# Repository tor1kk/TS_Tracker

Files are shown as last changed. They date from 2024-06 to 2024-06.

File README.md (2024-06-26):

# TheftShield_Tracker - GPS tracker with SMS communication 

## Brief

TheftShield Tracker is a device designed to provide real-time tracking and monitoring capabilities for valuable assets or vehicles. It leverages the power of GPS technology, GSM communication, and a microcontroller to offer a comprehensive solution for theft prevention and location tracking.

## Usage Instructions

To use the TheftShield Tracker, follow these steps:

1. **Insert SIM Card**:
    - Insert a nano SIM card into the SIM card slot of the device. Ensure that the SIM card does not have a PIN code set.

2. **Restart the Module**:
    - Restart the module by shorting the NRST and GND pins. This will reset the device and prepare it for operation.

3. **Wait for GPS Initialization**:
    - After restarting, the module will wait until the GPS module acquires a valid location fix. This might take a few minutes, especially in a new location or if the device has been off for a long time.

4. **GSM Module Network Registration**:
    - The GSM module will begin registering with the network. You can monitor the registration process by observing the LED indicator on the module:
        - **Fast blinking** (once every second): The module is searching for or trying to connect to a network.
        - **Slow blinking** (once every 3 seconds): The module is connected to the network.

5. **Send Commands**:
    - Once the device is connected to the network, you can start sending SMS commands to it. Note that the first command you send is usually ignored, so you might need to send it a second time.
    
## Features

The TheftShield Tracker offers the following key features:

- **GPS Tracking**: The device is equipped with a NEO-6M GPS module from u-blox, allowing it to accurately determine its geographic coordinates (latitude and longitude). The NEO-6M is a high-performance GPS receiver with excellent sensitivity and low power consumption.
- **GSM Communication**: The SIM800C GSM module from SIMCOM enables the device to send and receive SMS messages, facilitating remote control and data transmission. The SIM800C is a quad-band GSM/GPRS module that supports voice, SMS, and data transfer.
- **Real-Time Location Updates**: Upon receiving an SMS command, the device can promptly send its current GPS coordinates to a specified phone number.
- **Battery Voltage Monitoring**: The device can measure and report the battery voltage level to a specified phone number, ensuring timely monitoring of the power supply. It uses the built-in Analog-to-Digital Converter (ADC) of the STM32F401RCT6 microcontroller to measure the battery voltage.
- **RTC Alarm Configuration**: Users can set an alarm time through an SMS command. When the alarm triggers, the device will automatically send its GPS coordinates to a predefined phone number. The device utilizes the Real-Time Clock (RTC) peripheral of the STM32F401RCT6 microcontroller to set and manage the alarm.
- **Alarm Time Management**: The device allows users to request the current configured alarm time or deactivate the alarm through SMS commands.
- **Power Management**: The device can enter low-power sleep mode when idle, conserving battery life and extending operational duration. The STM32F401RCT6 microcontroller supports various low-power modes, allowing the device to minimize power consumption when not actively performing tasks.

**Here's a table of the supported SMS commands:**

| Command | Format | Description |
|---|---|---|
| Get GPS Coordinates  | 1: | Sends the device's current GPS coordinates to the specified phone number. |
| Get Voltage | 2: | Sends the battery voltage level to the specified phone number. |
| Set Alarm Time | 3:time: | Sets the RTC alarm time in 24-hour format (e.g., 3:2359: for 11:59 PM). The device will send GPS coordinates to the specified phone number when the alarm triggers. |
| Get Alarm Time | 4: | Requests the currently configured RTC alarm time. |
| Deactivate Alarm | 5: | Deactivates the RTC alarm. |

The device is powered by a backup battery and incorporates power management features to extend its operational lifetime. It utilizes the FreeRTOS real-time operating system to manage tasks and ensure efficient resource allocation.

With its combination of GPS tracking, GSM communication, and remote control capabilities, the TheftShield Tracker offers a reliable and versatile solution for asset tracking, theft prevention, and location monitoring applications.

## Photos

### 3D Model

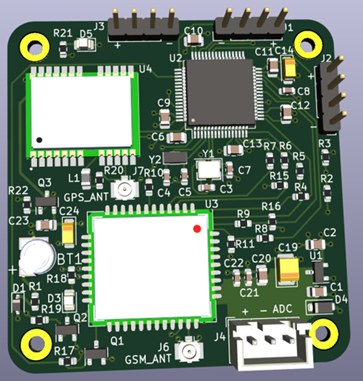
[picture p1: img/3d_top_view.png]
3D Model GPS tracker front view

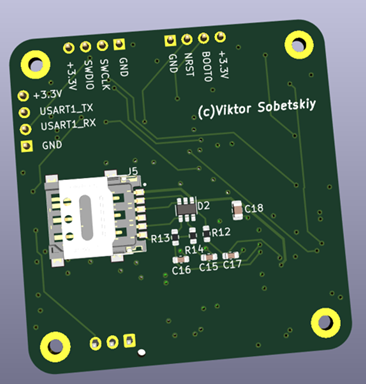
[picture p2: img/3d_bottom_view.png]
3D Model GPS tracker bottom view


### Real PCB

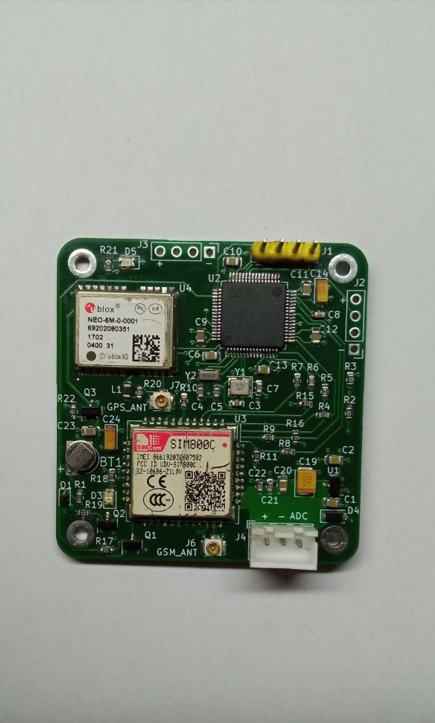
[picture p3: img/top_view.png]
Real PCB GPS tracker front view
<br/> 
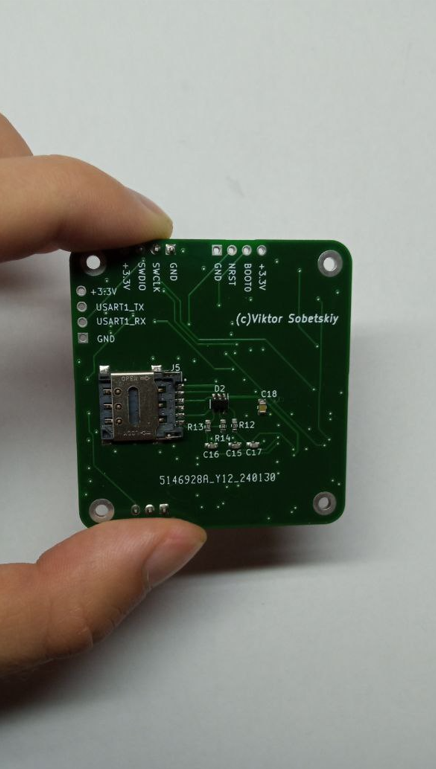
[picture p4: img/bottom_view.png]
Real PCB GPS tracker bottom view
 

# Project Structure

The project is organized into two main parts:

TheftShield_Tracker/<br/>
├── hardware/<br/>
│ └── README.md<br/>
└── software/<br/>
│└── README.md<br/>
└──
### hardware/
- **README.md**: Contains information about the hardware design.

### software/
- **README.md**: Contains information about the software implementation.

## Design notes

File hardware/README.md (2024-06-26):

# Hardware

## Brief

This directory contains the hardware design files for the TheftShield_Tracker project. The project utilizes the following key components:

**Microcontroller**

- STM32F401RCT6 - An ARM Cortex-M4 32-bit microcontroller from STMicroelectronics. It serves as the main control unit, handling task scheduling, communication with peripherals, and executing the application logic.

**GPS Module**

- NEO-6M - A high-performance GPS receiver module from u-blox. It provides accurate positioning data and enables tracking capabilities.

**GSM/GPRS Module**

- SIM800C - A quad-band GSM/GPRS module from SIMCOM. It enables SMS communication for remote control and data transmission.

**Other Components**

- MCP1700 - A low-dropout voltage regulator for providing a stable 3.3V supply.
- Backup battery holder and protection circuitry.
- Assorted passive components (resistors, capacitors, etc.).

## Design Files

- The KiCad project files containing the complete hardware design.
- [GPS tracker schematic](./TheftShield_Tracker.pdf) - A PDF version of the schematic.

## Block diagram

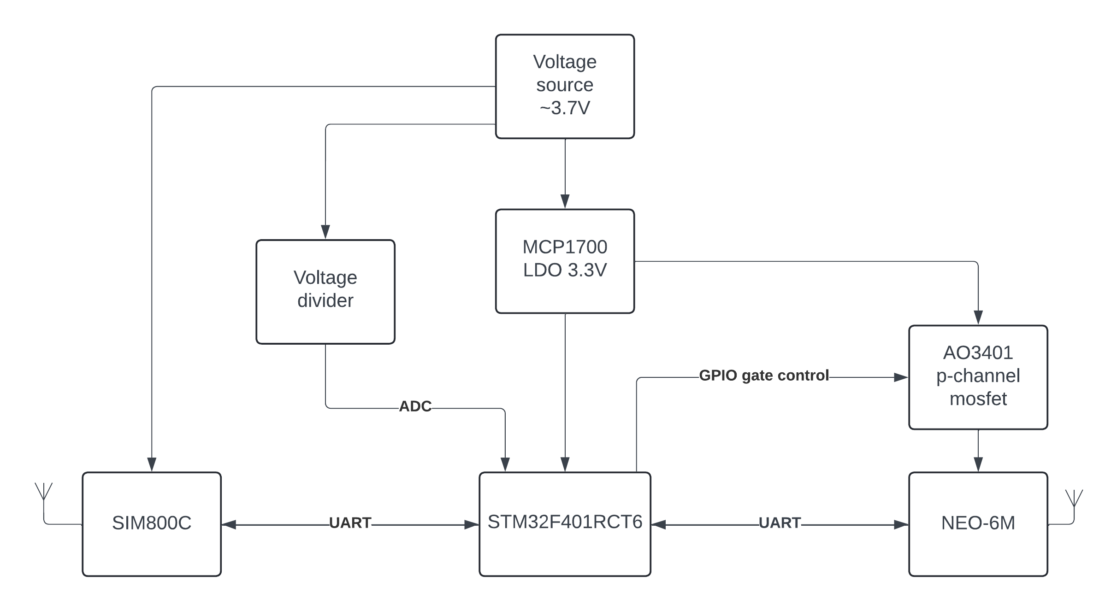
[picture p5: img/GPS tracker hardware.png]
GPS tracker hardware block diagram


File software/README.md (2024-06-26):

# Software

## Brief

The primary goal of this software is to receive commands from the SIM800C module, parse these commands, perform various actions (e.g., send GPS coordinates from the NEO-6M module), and send responses via the SIM800C module on the STM32F401RCT6 microcontroller.
For this project, appropriate drivers were written: [HAL-based NEO-6M driver](https://github.com/tor1kk/neo-6m) and [HAL-based SIM800C driver](https://github.com/tor1kk/sim800).

## How its work

After peripheral intitialisation, the current time is set for the RTC peripheral. A global variable (`currentTime`) is initialized to 0, and the program waits for this variable to become non-zero. This variable is modified in the ISR callback after receiving data from the GPS module, where the actual current time is obtained. Afterward, FreeRTOS tasks are created, and the scheduler is started. All tasks are located in the `application_tasks.c` file.

The first task to run is the one that resets and configures the SIM800C module (`vSim800ResetTask`).

Whenever an SMS message is received, the appropriate callback from the SIM800C driver (`SIM800_RcvdSMSCallBack`) is triggered. In this callback, the message and phone number are copied to send this data to a special task (`vCmdProcessTask`) via a queue (`xCommandQueue`). After that, this task is awakened from the blocked state to the ready state. This task parses the message; all commands should be digits, so the received command is compared with the expected commands. If they match, the appropriate action occurs. If the command doesn't match, the message `"Unknown command!"` is transmitted.

Users can send commands to get GPS coordinates, get the voltage on the ADC pin, set the time when coordinates will be received, get a notification for this time, or delete the notification.

### Tasks

- **vSim800ResetTask** - Resets and configures the SIM800 module (priority: `4`)
- **vCmdProcessTask** - Parses received commands (priority: `3`)
- **vSendSMSTask** - Transmits SMS messages (priority: `2`)
- **vConfigRTCAlarmTask** - Configures the RTC alarm (priority: `1`)
- **vSendGPSTask** - Gets the current GPS coordinates and sends them to **vSendSMSTask** (priority: `1`)
- **vSendVoltageTask** - Gets the voltage on the ADC pin and sends it to **vSendSMSTask** (priority: `1`)
- **vSendCurrentAlarmTask** - Gets the current RTC alarm and sends it to **vSendSMSTask** (priority: `1`)

Any data that must be transmitted to the user is sent to the `xSMSToSendQueue`, and `vSendSMSTask` receives this data and sends it to the user.

`vConfigRTCAlarmTask` waits for the time at which the RTC alarm must occur in the `xTimeToRTCAlarmQueue`. It should be noted that when the RTC alarm triggers, the phone number contained in the `phoneNumberForNotify` buffer, which was placed there by `vCmdProcessTask`, is used. This is the number from which the notification command was received.

`vSendGPSTask` waits for numbers to which coordinates must be sent in the `xNumbersToSendGPSQueue`. In this task, the NEO-6M module is powered on and GPS coordinates are awaited in the `xGPSCoordinatesQueue`, which are set in the `NEO6M_RMCCallBack` callback from the NEO-6M driver. Then, an SMS message with the coordinates and number is sent to `vSendSMSTask`.

`vSendVoltageTask` waits for numbers to which the voltage must be sent in the `xNumbersToSendVoltageQueue`. In this task, an ADC conversion is initiated and the voltage value is awaited in the `xADCValueQueue`, which is placed in the `HAL_ADC_ConvCpltCallback`. Then, an SMS message with the voltage and number is sent to `vSendSMSTask`.

`vSendCurrentAlarmTask` waits for a notification from `vCmdProcessTask`. It gets the current RTC alarm and sends this information to the number in the `phoneNumberForNotify` buffer. 

### Block diagram

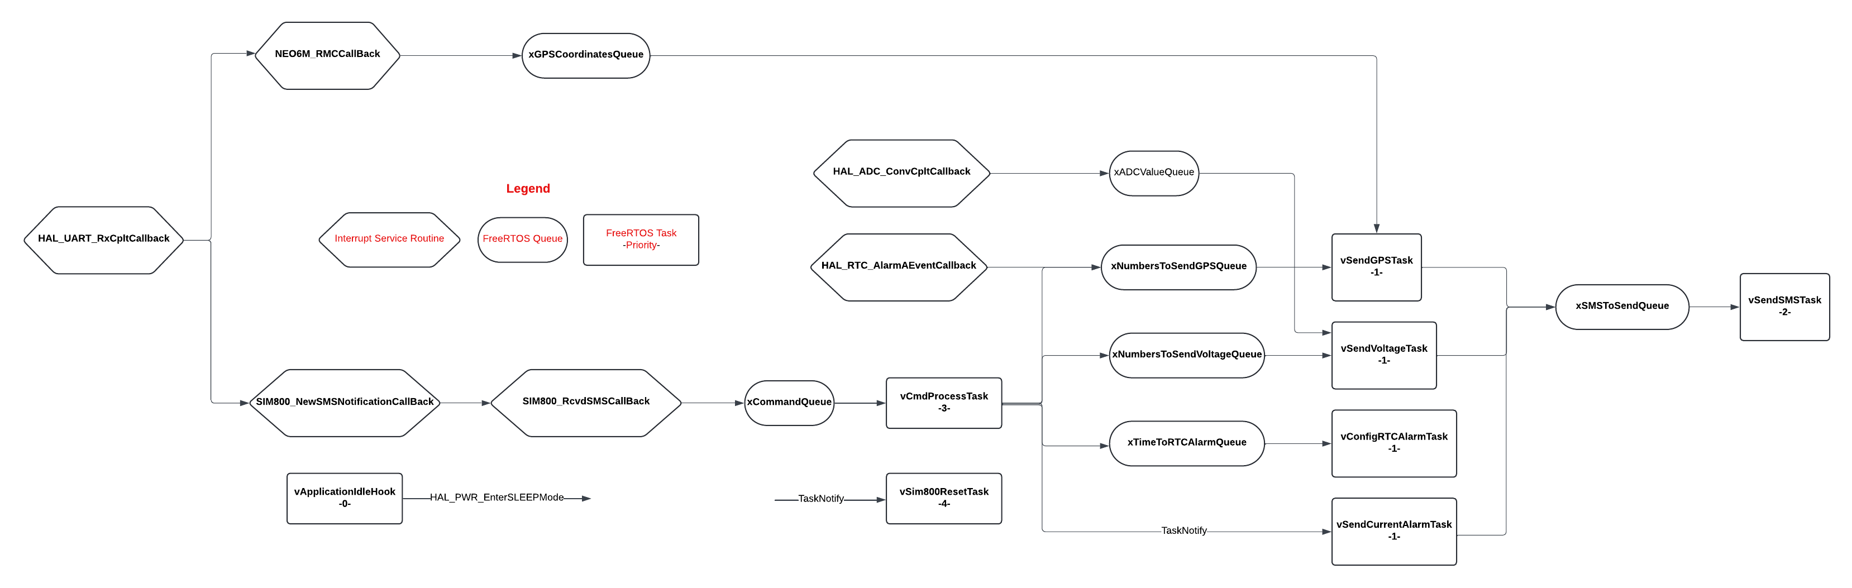
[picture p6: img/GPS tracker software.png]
GPS tracker FreeRTOS software block diagram


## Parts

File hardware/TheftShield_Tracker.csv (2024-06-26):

Reference | Value | Footprint | Qty
BT1 | Battery_Cell | footprints:SEIKO_ML414H_IV01E | 1
C1,C2,C20 | 1uF | Capacitor_SMD:C_0805_2012Metric | 3
C3,C4,C5,C7,C22 | 12pF | Capacitor_SMD:C_0603_1608Metric | 5
C6,C9,C10,C11,C12,C13,C18,C23 | 100nF | Capacitor_SMD:C_0805_2012Metric | 8
C8,C14,C24 | 4,7uF | -- mixed values -- | 3
C15,C16,C17,C21 | 22pF | Capacitor_SMD:C_0603_1608Metric | 4
C19 | 100uF | Capacitor_Tantalum_SMD:CP_EIA-3528-21_Kemet-B | 1
D1 | 1N5819WS | Diode_SMD:D_SOD-323 | 1
D2 | ESDA6V1-5SC6 | Package_TO_SOT_SMD:SOT-23-6 | 1
D3,D5 | ncd0805r1 | LED_SMD:LED_0805_2012Metric | 2
D4 | BZT52B5V1 | Diode_SMD:D_SOD-123F | 1
H1,H2,H3,H4 | MountingHole_Pad | MountingHole:MountingHole_2.2mm_M2_Pad | 4
J1,J2,J3 | Conn_01x04_Pin | Connector_PinHeader_2.54mm:PinHeader_1x04_P2.54mm_Vertical | 3
J4 | Conn_01x03_Socket | Connector_JST:JST_XH_B3B-XH-AM_1x03_P2.50mm_Vertical | 1
J5 | SIM8060-6-1-14-00-A | footprints:GCT_SIM8060-6-1-14-00-A | 1
J6,J7 | Conn_Coaxial | Connector_Coaxial:U.FL_Hirose_U.FL-R-SMT-1_Vertical | 2
L1 | 22uH | Inductor_SMD:L_0805_2012Metric | 1
Q1,Q2 | AO3402 | Package_TO_SOT_SMD:SOT-23 | 2
Q3 | AO3401A | Package_TO_SOT_SMD:SOT-23 | 1
R1,R4,R5,R6,R7,R8,R9,R10,R18,R21 | 1K | Resistor_SMD:R_0603_1608Metric | 10
R2,R3,R17,R19,R22 | 47K | Resistor_SMD:R_0603_1608Metric | 5
R11,R15,R16 | 5.1K | Resistor_SMD:R_0603_1608Metric | 3
R12,R13,R14 | 51R | Resistor_SMD:R_0603_1608Metric | 3
R20 | 22R | Resistor_SMD:R_0603_1608Metric | 1
U1 | MCP1700x-330xxTT | Package_TO_SOT_SMD:SOT-23 | 1
U2 | STM32F401RCTx | Package_QFP:LQFP-64_10x10mm_P0.5mm | 1
U3 | SIM800C | RF_GSM:SIMCom_SIM800C | 1
U4 | NEO-6M-GPS | footprints:XCVR_NEO-6M-GPS | 1
Y1 | Crystal_GND24 | Crystal:Crystal_SMD_3225-4Pin_3.2x2.5mm | 1
Y2 | 32.768kHz | Crystal:Crystal_SMD_3215-2Pin_3.2x1.5mm | 1

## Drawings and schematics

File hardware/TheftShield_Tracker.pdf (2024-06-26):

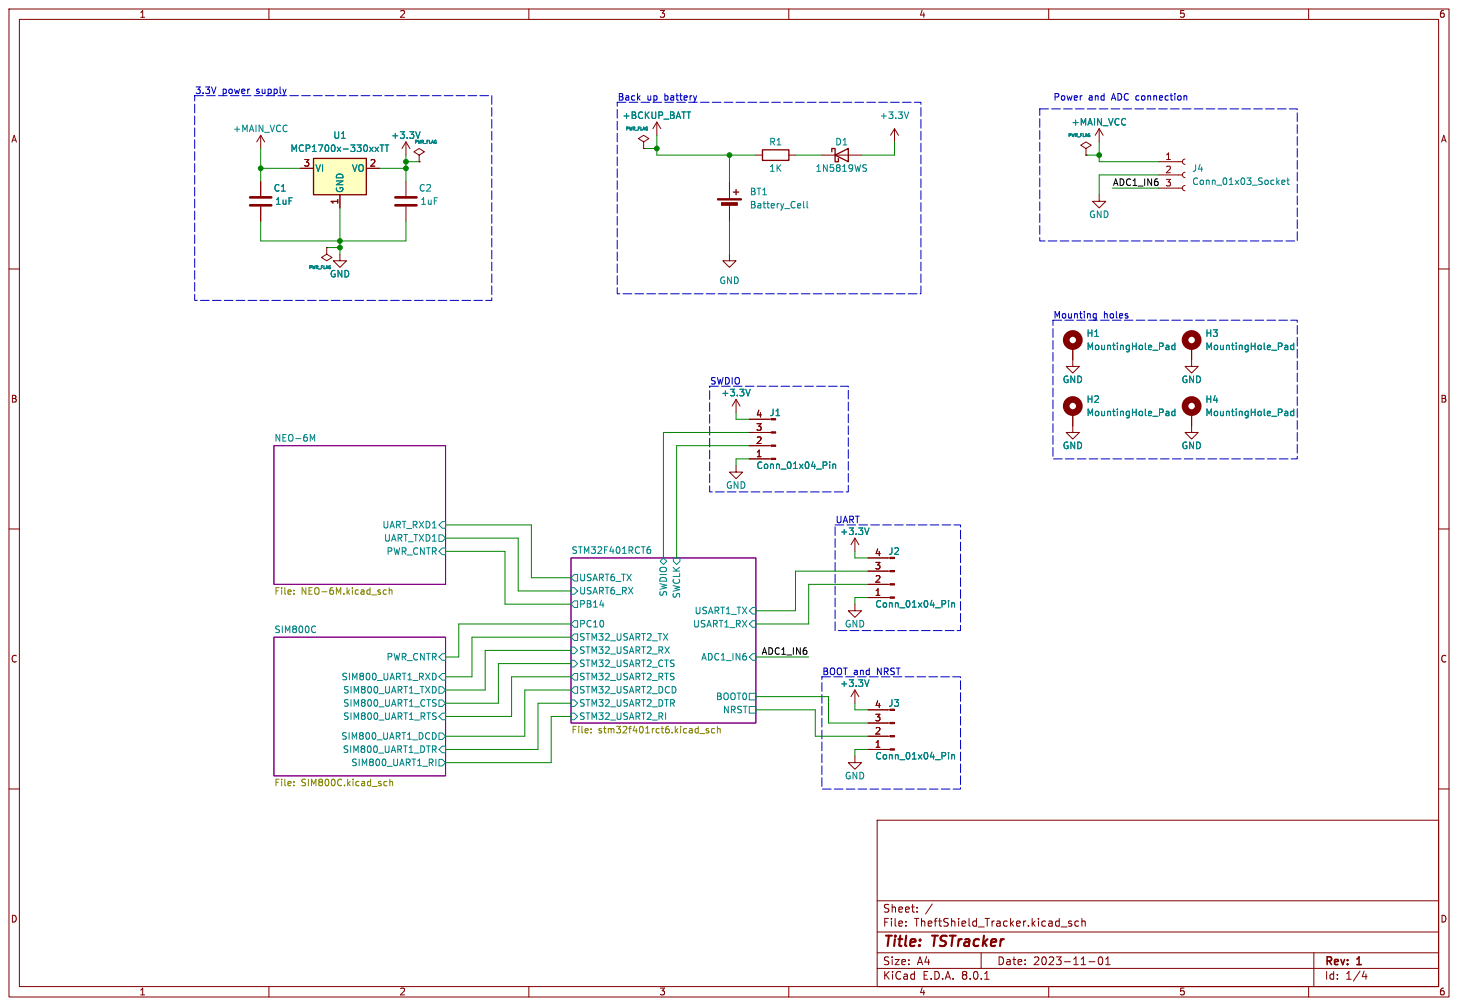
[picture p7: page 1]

Id: 1/4 Title: TSTracker File: TheftShield_Tracker.kicad_sch Sheet: / UART_RXD1 UART_TXD1 PWR_CNTR

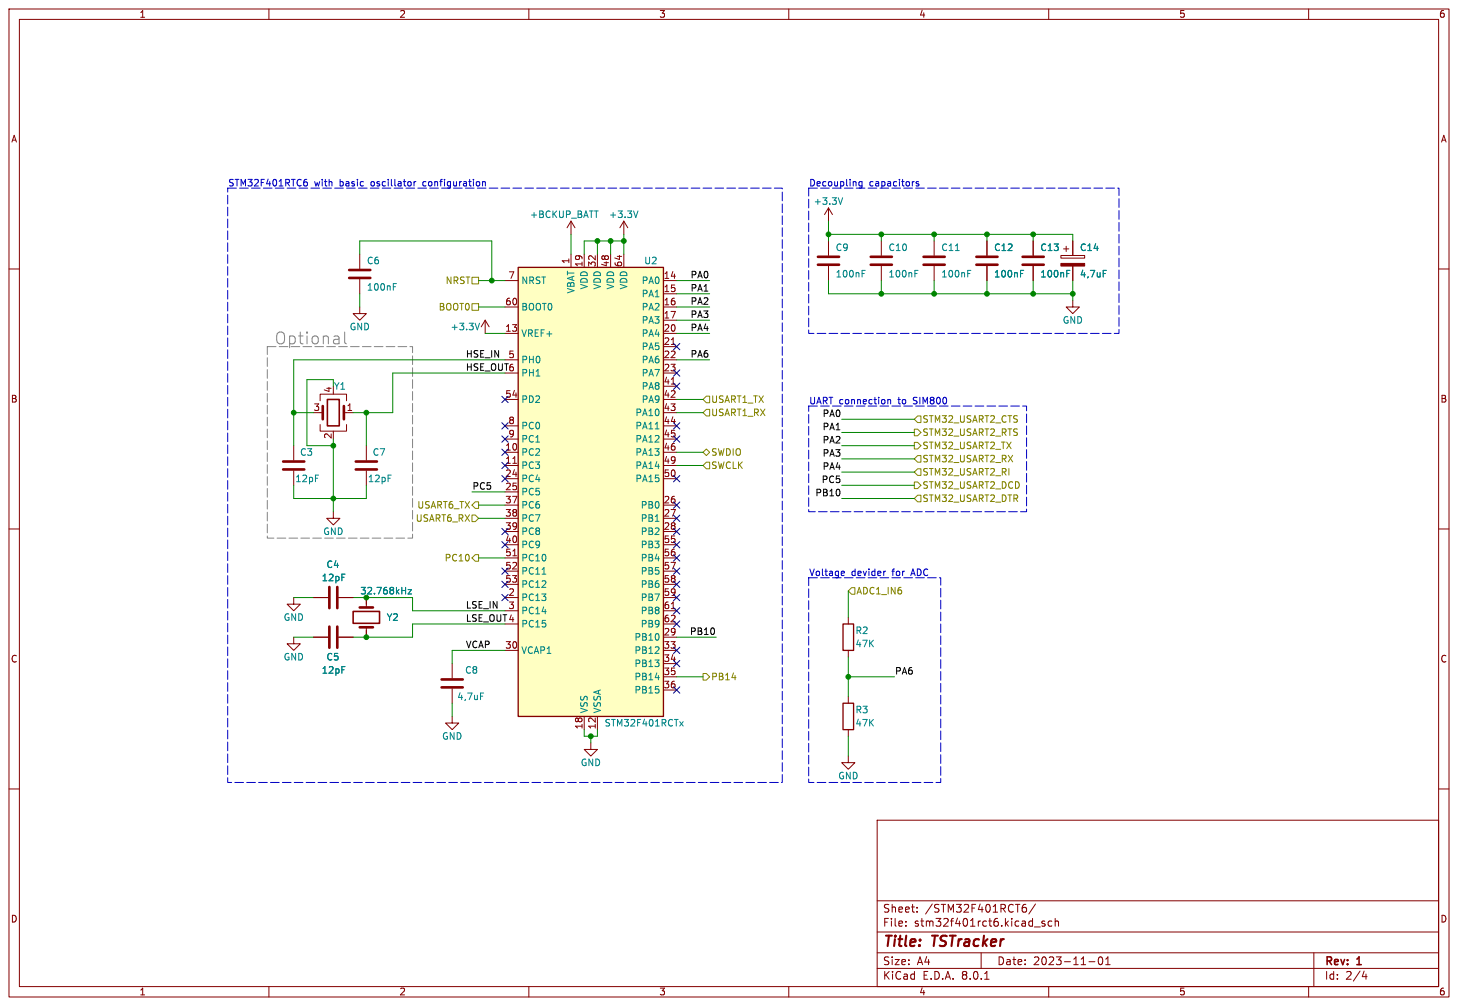
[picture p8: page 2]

1 PC2 10 PC3 11 VSSA 12 VREF+ 13 PA0 14 PA1 15 PA2 16 PA3 17 VSS 18 VDD 19 PC13 2 PA4 20 PA5 21 PA6 22 PA7 23 PC4 24 PC5 25 PB0 26 PB1 27 PB2 28 PB10 29 PC14 3 VCAP1 30 VDD 32 PB12 33 PB13 34 PB14 35 PB15 36 PC6 37 PC7 38 PC8 39 PC15 4 PC9 40 PA8 41 PA9 42 PA10 43 PA11 44 PA12 45 PA13 46 VDD 48 PA14 49 PH0 5 PA15 50 PC10 51 PC11 52 PC12 53 PD2 54 PB3 55 PB4 56 PB5 57 PB6 58 PB7 59 PH1 6 BOOT0 60 PB8 61 PB9 62 VDD 64 NRST 7 PC0 8 PC1 9 U2 STM32F401RCTx GND GND

Id: 2/4 Title: TSTracker File: stm32f401rct6.kicad_sch Sheet: /STM32F401RCT6/

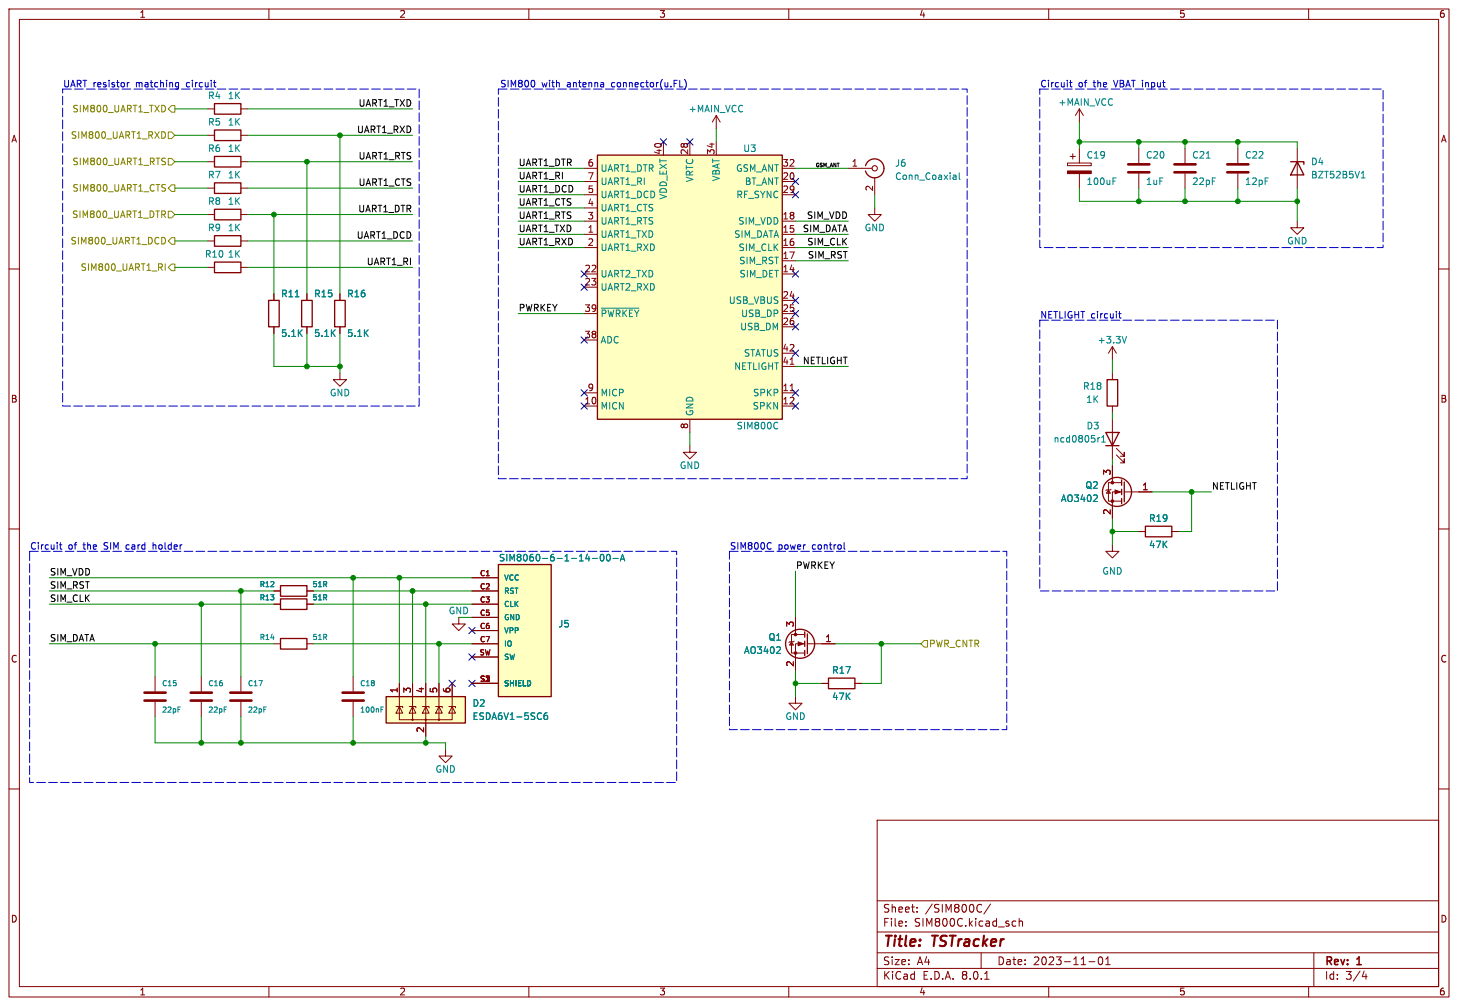
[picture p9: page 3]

SIM800 with antenna connector(u.FL) D2ESDA6V1-5SC6
J6Conn_Coaxial GND
GSM_ANT NETLIGHT SIM_VDD

Id: 3/4 Title: TSTracker File: SIM800C.kicad_sch Sheet: /SIM800C/ C17

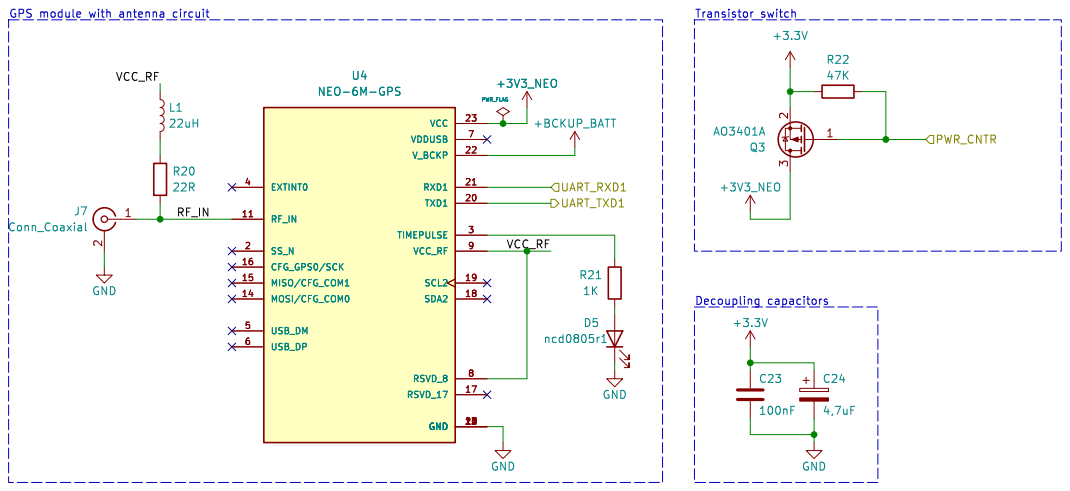
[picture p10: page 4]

Id: 4/4 Title: TSTracker File: NEO-6M.kicad_sch Sheet: /NEO-6M/

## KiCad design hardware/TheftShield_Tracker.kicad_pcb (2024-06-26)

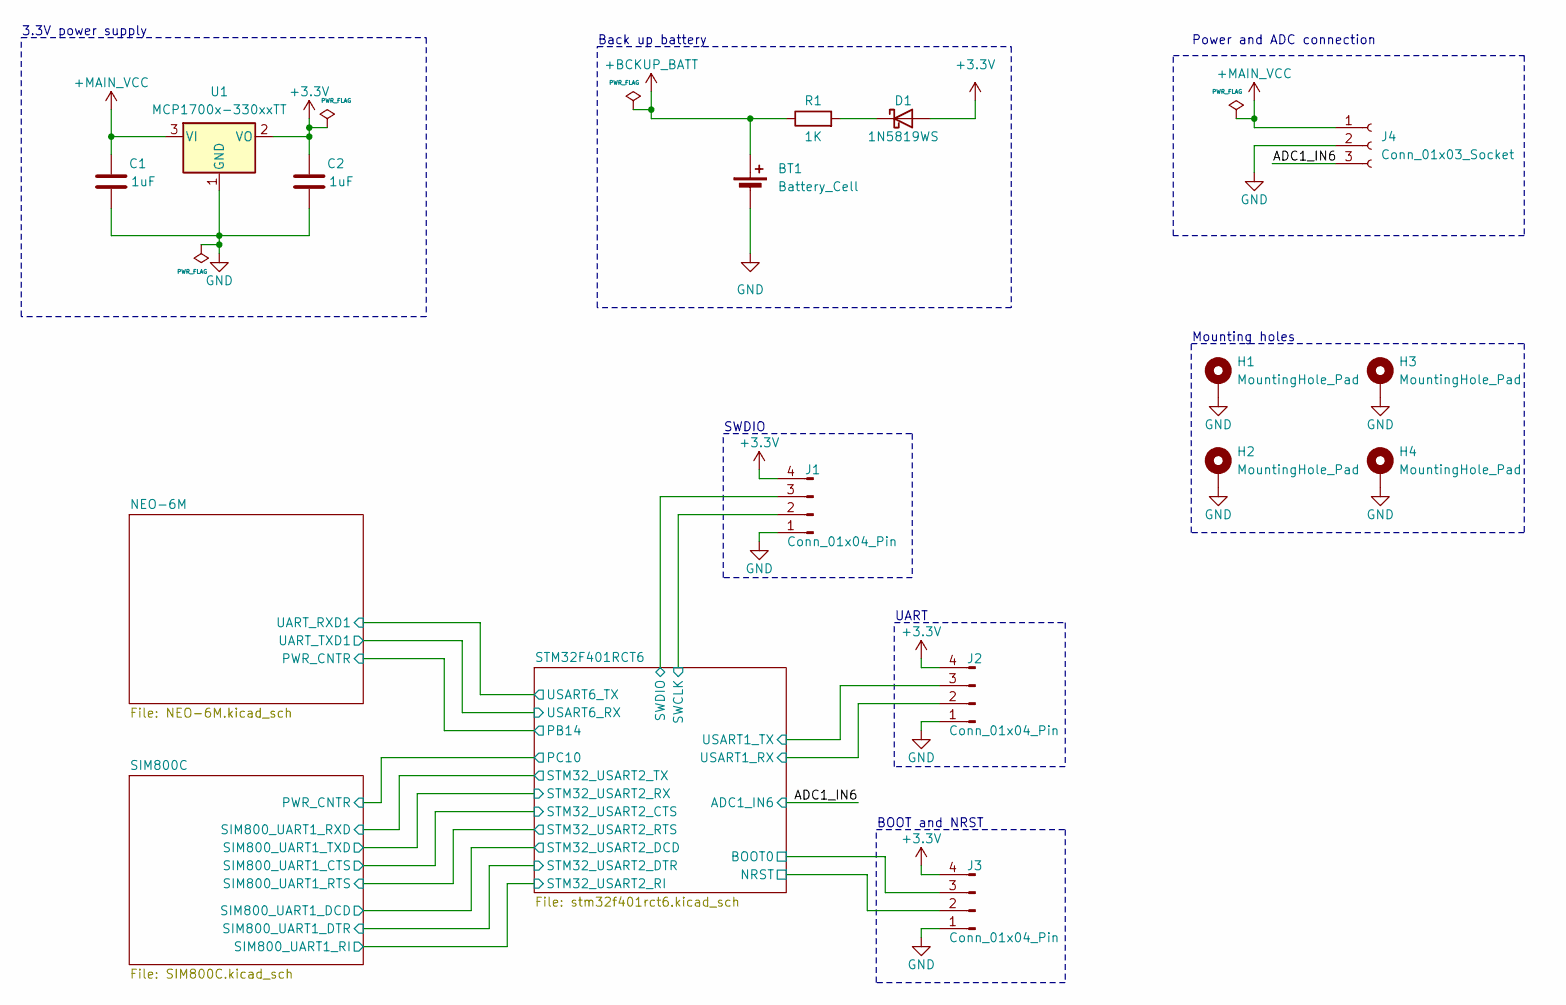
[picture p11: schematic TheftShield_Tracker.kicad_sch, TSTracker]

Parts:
BT1: Battery_Cell; SEIKO_ML414H_IV01E
C1, C2: 1uF; C_0805_2012Metric
D1: 1N5819WS; D_SOD-323
H1, H2, H3, H4: MountingHole_Pad; MountingHole_2.2mm_M2_Pad
J1, J2, J3: Conn_01x04_Pin; PinHeader_1x04_P2.54mm_Vertical
J4: Conn_01x03_Socket; JST_XH_B3B-XH-AM_1x03_P2.50mm_Vertical
R1: 1K; R_0603_1608Metric
U1: MCP1700x-330xxTT; SOT-23

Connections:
+3.3V: C2.2, D1.2 (A), J1.4, J2.4, J3.4, U1.2 (VO); also elsewhere on the board
+BCKUP_BATT: BT1.1 (+), R1.1; also elsewhere on the board
+MAIN_VCC: C1.2, J4.1, U1.3 (VI); also elsewhere on the board
/ADC1_IN6: J4.3; also elsewhere on the board
/STM32F401RCT6/BOOT0: J3.3; also elsewhere on the board
/STM32F401RCT6/NRST: J3.2; also elsewhere on the board
/STM32F401RCT6/SWCLK: J1.2; also elsewhere on the board
/STM32F401RCT6/SWDIO: J1.3; also elsewhere on the board
/STM32F401RCT6/USART1_RX: J2.2; also elsewhere on the board
/STM32F401RCT6/USART1_TX: J2.3; also elsewhere on the board
GND: BT1.2 (-), C1.1, C2.1, H1.1, H2.1, H3.1, H4.1, J1.1, J2.1, J3.1, J4.2, U1.1 (GND); also elsewhere on the board
unnamed: D1.1 (K), R1.2

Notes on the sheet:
Power and ADC connection
BOOT and NRST
Mounting holes
SWDIO
Back up battery
3.3V power supply
UART

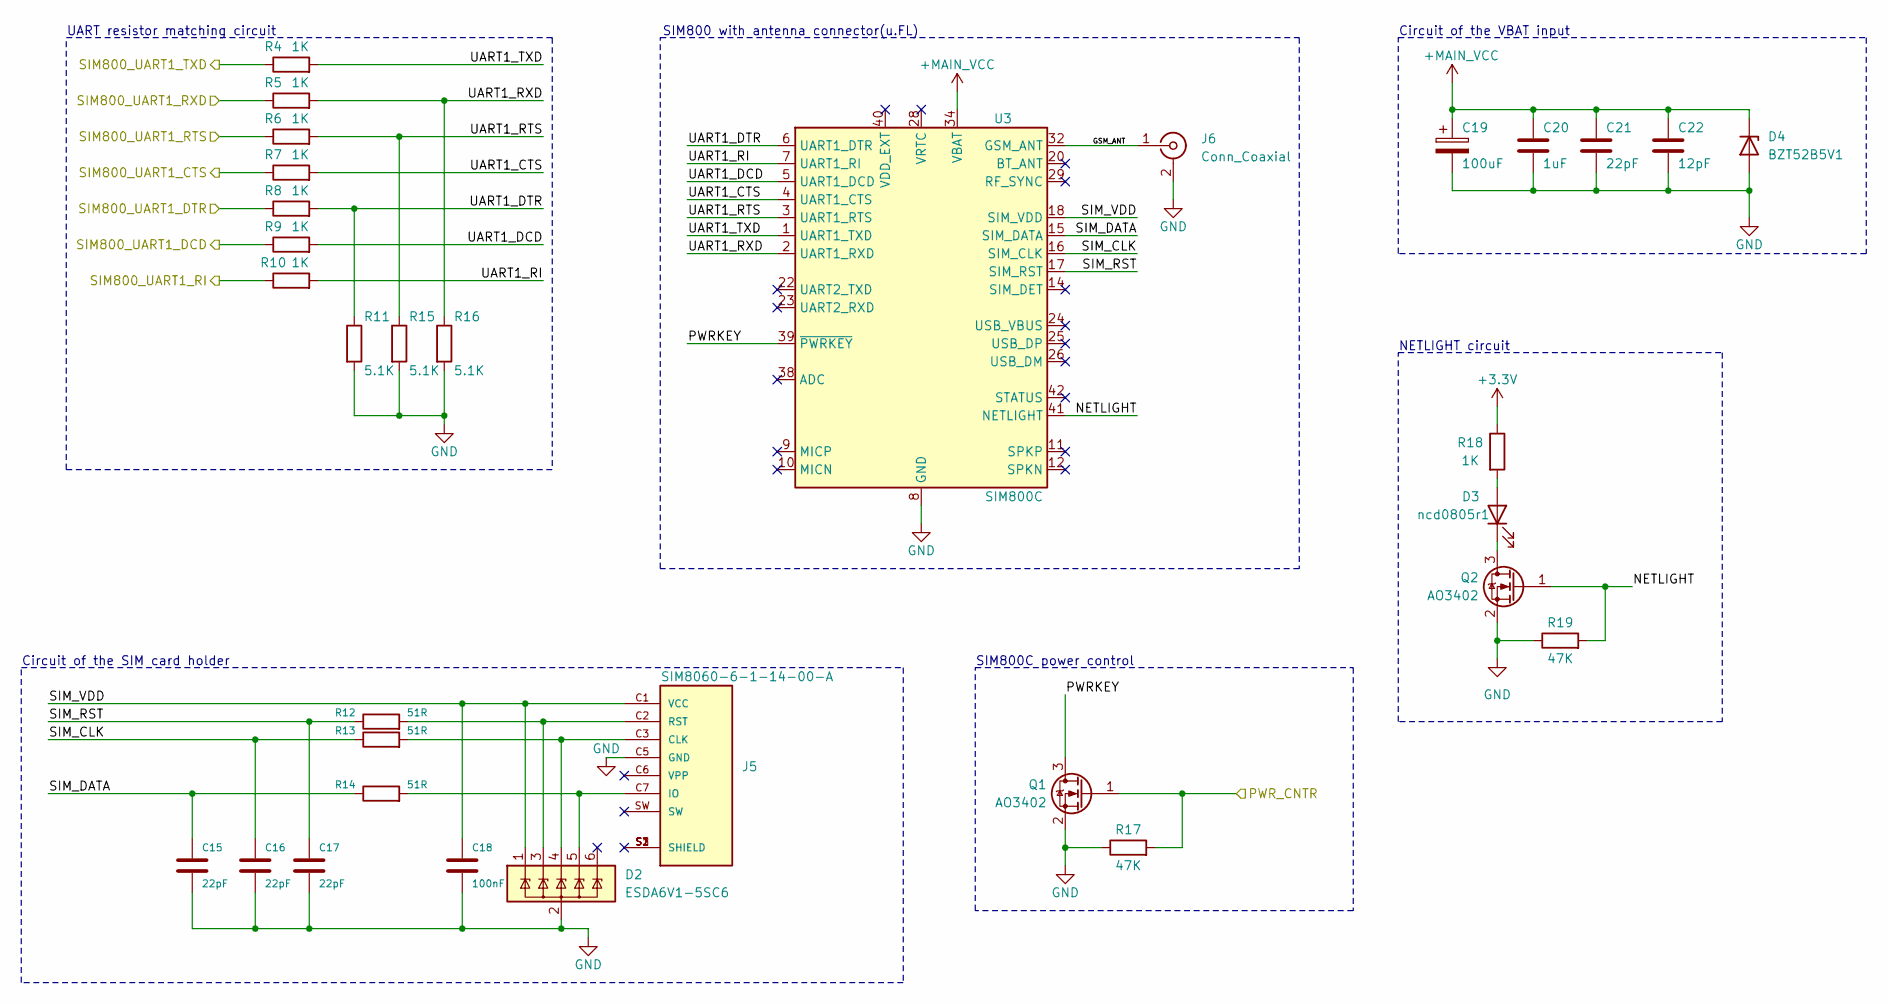
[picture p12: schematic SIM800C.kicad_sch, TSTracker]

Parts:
C15, C16, C17, C21: 22pF; C_0603_1608Metric
C18: 100nF; C_0805_2012Metric
C19: 100uF; CP_EIA-3528-21_Kemet-B
C20: 1uF; C_0805_2012Metric
C22: 12pF; C_0603_1608Metric
D2: ESDA6V1-5SC6; SOT-23-6
D3: ncd0805r1; LED_0805_2012Metric
D4: BZT52B5V1; D_SOD-123F
J5: SIM8060-6-1-14-00-A; GCT_SIM8060-6-1-14-00-A; PARTREV A
J6: Conn_Coaxial; U.FL_Hirose_U.FL-R-SMT-1_Vertical
Q1, Q2: AO3402; SOT-23
R4, R5, R6, R7, R8, R9, R10, R18: 1K; R_0603_1608Metric
R11, R15, R16: 5.1K; R_0603_1608Metric
R12, R13, R14: 51R; R_0603_1608Metric
R17, R19: 47K; R_0603_1608Metric
U3: SIM800C; SIMCom_SIM800C

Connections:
+3.3V: R18.1; also elsewhere on the board
+MAIN_VCC: C19.1, C20.1, C21.1, C22.1, D4.1 (K), U3.34 (VBAT), U3.35 (VBAT); also elsewhere on the board
/SIM800C/GSM_ANT: J6.1 (In), U3.32 (GSM_ANT)
/SIM800C/NETLIGHT: Q2.1 (G), R19.2, U3.41 (NETLIGHT)
/SIM800C/PWRKEY: Q1.3 (D), U3.39 (~PWRKEY)
/SIM800C/PWR_CNTR: Q1.1 (G), R17.2; also elsewhere on the board
/SIM800C/SIM_CLK: C16.1, R13.1, U3.16 (SIM_CLK)
/SIM800C/SIM_DATA: C15.1, R14.1, U3.15 (SIM_DATA)
/SIM800C/SIM_RST: C17.1, R12.1, U3.17 (SIM_RST)
/SIM800C/SIM_VDD: C18.1, D2.1 (IO1), J5.C1 (VCC), U3.18 (SIM_VDD)
/SIM800C/UART1_CTS: R7.2, U3.4 (UART1_CTS)
/SIM800C/UART1_DCD: R9.2, U3.5 (UART1_DCD)
/SIM800C/UART1_DTR: R8.2, R11.1, U3.6 (UART1_DTR)
/SIM800C/UART1_RI: R10.2, U3.7 (UART1_RI)
/SIM800C/UART1_RTS: R6.2, R15.1, U3.3 (UART1_RTS)
/SIM800C/UART1_RXD: R5.2, R16.1, U3.2 (UART1_RXD)
/SIM800C/UART1_TXD: R4.2, U3.1 (UART1_TXD)
/STM32F401RCT6/PA0: R7.1; also elsewhere on the board
/STM32F401RCT6/PA1: R6.1; also elsewhere on the board
/STM32F401RCT6/PA2: R5.1; also elsewhere on the board
/STM32F401RCT6/PA3: R4.1; also elsewhere on the board
/STM32F401RCT6/PA4: R10.1; also elsewhere on the board
/STM32F401RCT6/PB10: R8.1; also elsewhere on the board
/STM32F401RCT6/PC5: R9.1; also elsewhere on the board
GND: C15.2, C16.2, C17.2, C18.2, C19.2, C20.2, C21.2, C22.2, D2.2 (GND), D4.2 (A), J5.C5 (GND), J6.2 (Ext), Q1.2 (S), Q2.2 (S), R11.2, R15.2, R16.2, R17.1, R19.1, U3.8 (GND), U3.13 (GND), U3.19 (GND), U3.21 (GND), U3.27 (GND), U3.30 (GND), U3.31 (GND), U3.33 (GND), U3.36 (GND), U3.37 (GND); also elsewhere on the board
unnamed: D2.3 (IO2), J5.C2 (RST), R12.2
unnamed: D2.4 (IO3), J5.C3 (CLK), R13.2
unnamed: D2.5 (IO4), J5.C7 (IO), R14.2
unnamed: D3.2 (A), R18.2
unnamed: D3.1 (K), Q2.3 (D)

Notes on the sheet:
NETLIGHT circuit
Circuit of the VBAT input
UART resistor matching circuit
Circuit of the SIM card holder
SIM800 with antenna connector(u.FL)
SIM800C power control

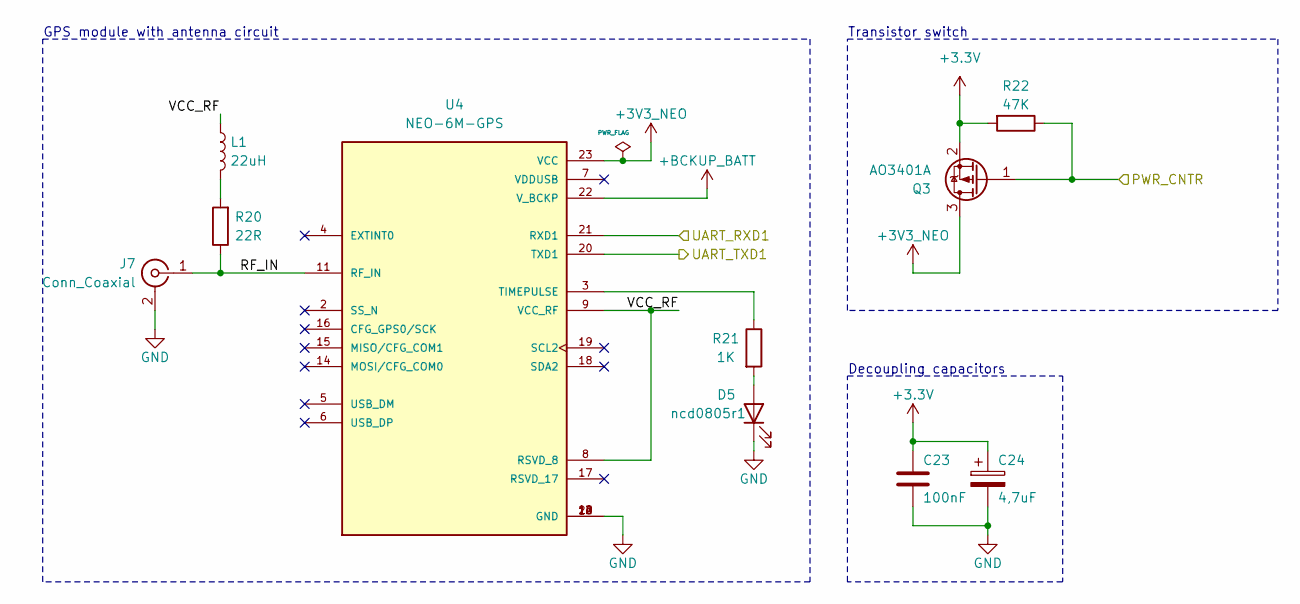
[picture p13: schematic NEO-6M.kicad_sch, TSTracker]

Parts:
C23: 100nF; C_0805_2012Metric
C24: 4,7uF; CP_EIA-3216-18_Kemet-A
D5: ncd0805r1; LED_0805_2012Metric
J7: Conn_Coaxial; U.FL_Hirose_U.FL-R-SMT-1_Vertical
L1: 22uH; L_0805_2012Metric
Q3: AO3401A; SOT-23
R20: 22R; R_0603_1608Metric
R21: 1K; R_0603_1608Metric
R22: 47K; R_0603_1608Metric
U4: NEO-6M-GPS; XCVR_NEO-6M-GPS; PARTREV R15

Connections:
+3.3V: C23.1, C24.1, Q3.2 (S), R22.2; also elsewhere on the board
+3V3_NEO: Q3.3 (D), U4.23 (VCC)
+BCKUP_BATT: U4.22 (V_BCKP); also elsewhere on the board
/NEO-6M/PWR_CNTR: Q3.1 (G), R22.1; also elsewhere on the board
/NEO-6M/RF_IN: J7.1 (In), R20.1, U4.11 (RF_IN)
/NEO-6M/UART_RXD1: U4.21 (RXD1); also elsewhere on the board
/NEO-6M/UART_TXD1: U4.20 (TXD1); also elsewhere on the board
/NEO-6M/VCC_RF: L1.1, U4.8 (RSVD_8), U4.9 (VCC_RF)
GND: C23.2, C24.2, D5.1 (K), J7.2 (Ext), U4.10 (GND), U4.12 (GND), U4.13 (GND), U4.24 (GND); also elsewhere on the board
unnamed: D5.2 (A), R21.2
unnamed: L1.2, R20.2
unnamed: R21.1, U4.3 (TIMEPULSE)

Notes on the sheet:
Decoupling capacitors
GPS module with antenna circuit
Transistor switch

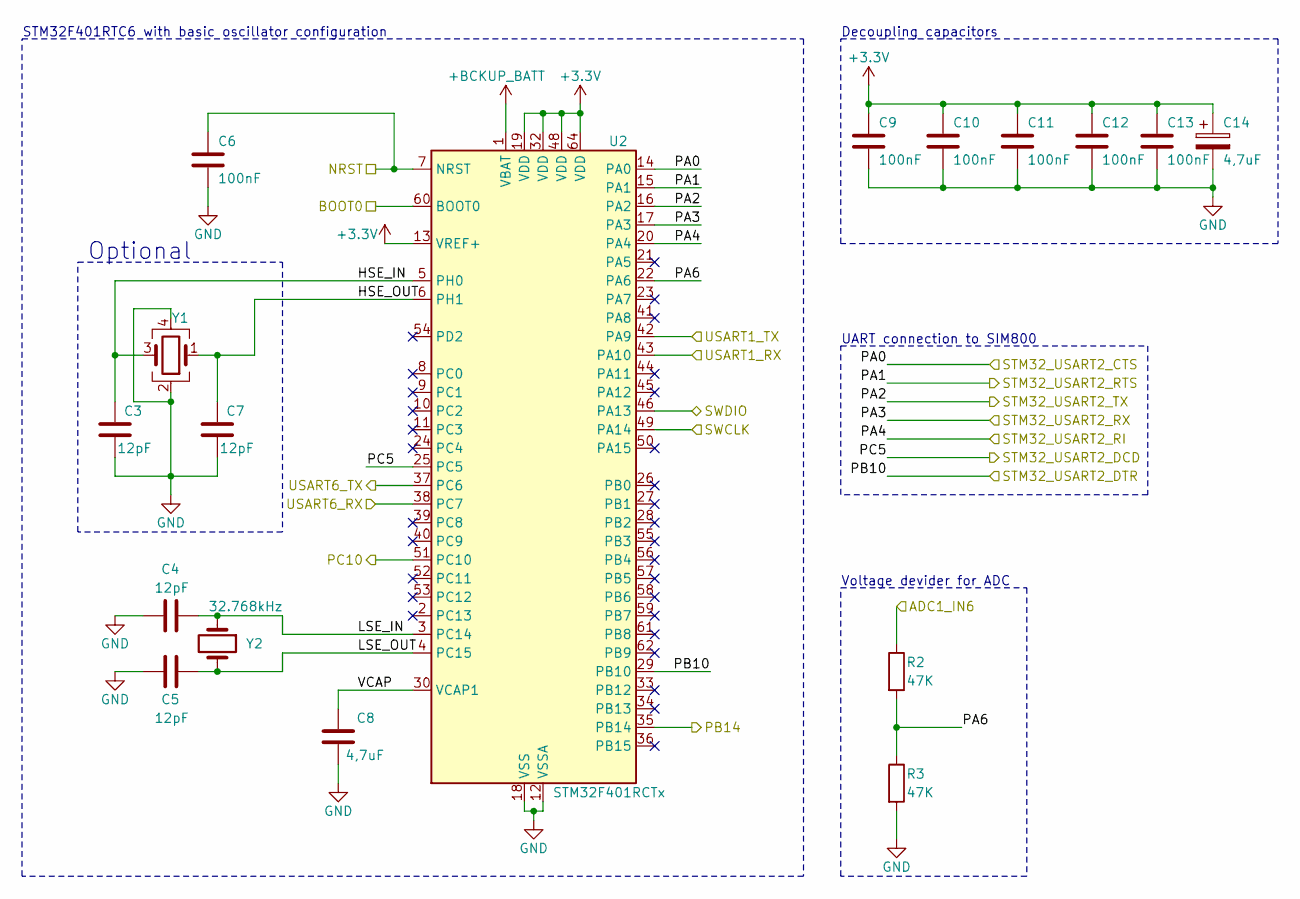
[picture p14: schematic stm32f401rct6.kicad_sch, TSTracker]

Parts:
C3, C4, C5, C7: 12pF; C_0603_1608Metric
C6, C9, C10, C11, C12, C13: 100nF; C_0805_2012Metric
C8: 4,7uF; C_0603_1608Metric
C14: 4,7uF; CP_EIA-3216-18_Kemet-A
R2, R3: 47K; R_0603_1608Metric
U2: STM32F401RCTx; LQFP-64_10x10mm_P0.5mm
Y1: Crystal_GND24; Crystal_SMD_3225-4Pin_3.2x2.5mm
Y2: 32.768kHz; Crystal_SMD_3215-2Pin_3.2x1.5mm

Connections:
+3.3V: C9.1, C10.1, C11.1, C12.1, C13.1, C14.1, U2.13 (VREF+), U2.19 (VDD), U2.32 (VDD), U2.48 (VDD), U2.64 (VDD); also elsewhere on the board
+BCKUP_BATT: U2.1 (VBAT); also elsewhere on the board
/ADC1_IN6: R2.1; also elsewhere on the board
/NEO-6M/PWR_CNTR: U2.35 (PB14); also elsewhere on the board
/NEO-6M/UART_RXD1: U2.37 (PC6); also elsewhere on the board
/NEO-6M/UART_TXD1: U2.38 (PC7); also elsewhere on the board
/SIM800C/PWR_CNTR: U2.51 (PC10); also elsewhere on the board
/STM32F401RCT6/BOOT0: U2.60 (BOOT0); also elsewhere on the board
/STM32F401RCT6/HSE_IN: C3.2, U2.5 (PH0), Y1.3
/STM32F401RCT6/HSE_OUT: C7.2, U2.6 (PH1), Y1.1
/STM32F401RCT6/LSE_IN: C4.2, U2.3 (PC14), Y2.1
/STM32F401RCT6/LSE_OUT: C5.2, U2.4 (PC15), Y2.2
/STM32F401RCT6/NRST: C6.1, U2.7 (NRST); also elsewhere on the board
/STM32F401RCT6/PA0: U2.14 (PA0); also elsewhere on the board
/STM32F401RCT6/PA1: U2.15 (PA1); also elsewhere on the board
/STM32F401RCT6/PA2: U2.16 (PA2); also elsewhere on the board
/STM32F401RCT6/PA3: U2.17 (PA3); also elsewhere on the board
/STM32F401RCT6/PA4: U2.20 (PA4); also elsewhere on the board
/STM32F401RCT6/PA6: R2.2, R3.1, U2.22 (PA6)
/STM32F401RCT6/PB0: U2.26 (PB0)
/STM32F401RCT6/PB1: U2.27 (PB1)
/STM32F401RCT6/PB10: U2.29 (PB10); also elsewhere on the board
/STM32F401RCT6/PC5: U2.25 (PC5); also elsewhere on the board
/STM32F401RCT6/SWCLK: U2.49 (PA14); also elsewhere on the board
/STM32F401RCT6/SWDIO: U2.46 (PA13); also elsewhere on the board
/STM32F401RCT6/USART1_RX: U2.43 (PA10); also elsewhere on the board
/STM32F401RCT6/USART1_TX: U2.42 (PA9); also elsewhere on the board
/STM32F401RCT6/VCAP: C8.2, U2.30 (VCAP1)
GND: C3.1, C4.1, C5.1, C6.2, C7.1, C8.1, C9.2, C10.2, C11.2, C12.2, C13.2, C14.2, R3.2, U2.12 (VSSA), U2.18 (VSS), U2.31 (VSS), U2.47 (VSS), U2.63 (VSS), Y1.2, Y1.4; also elsewhere on the board

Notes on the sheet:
Optional
Decoupling capacitors
STM32F401RTC6 with basic oscillator configuration
UART connection to SIM800
Voltage devider for ADC

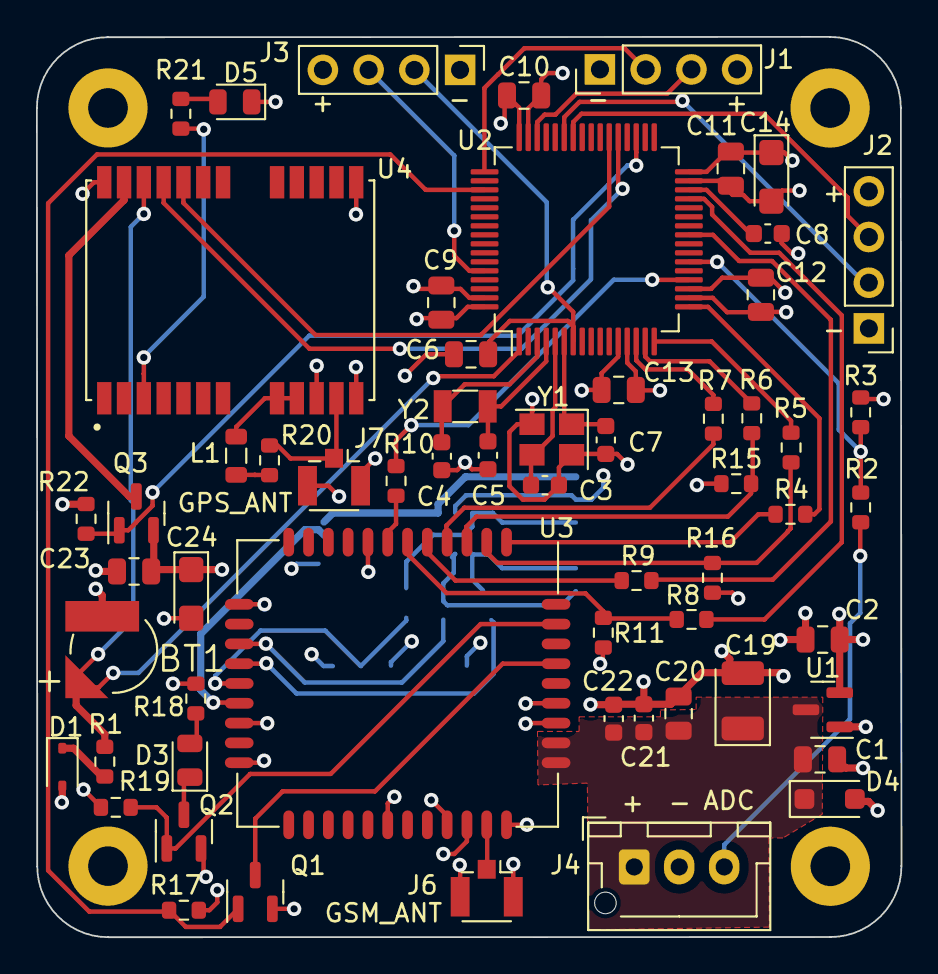
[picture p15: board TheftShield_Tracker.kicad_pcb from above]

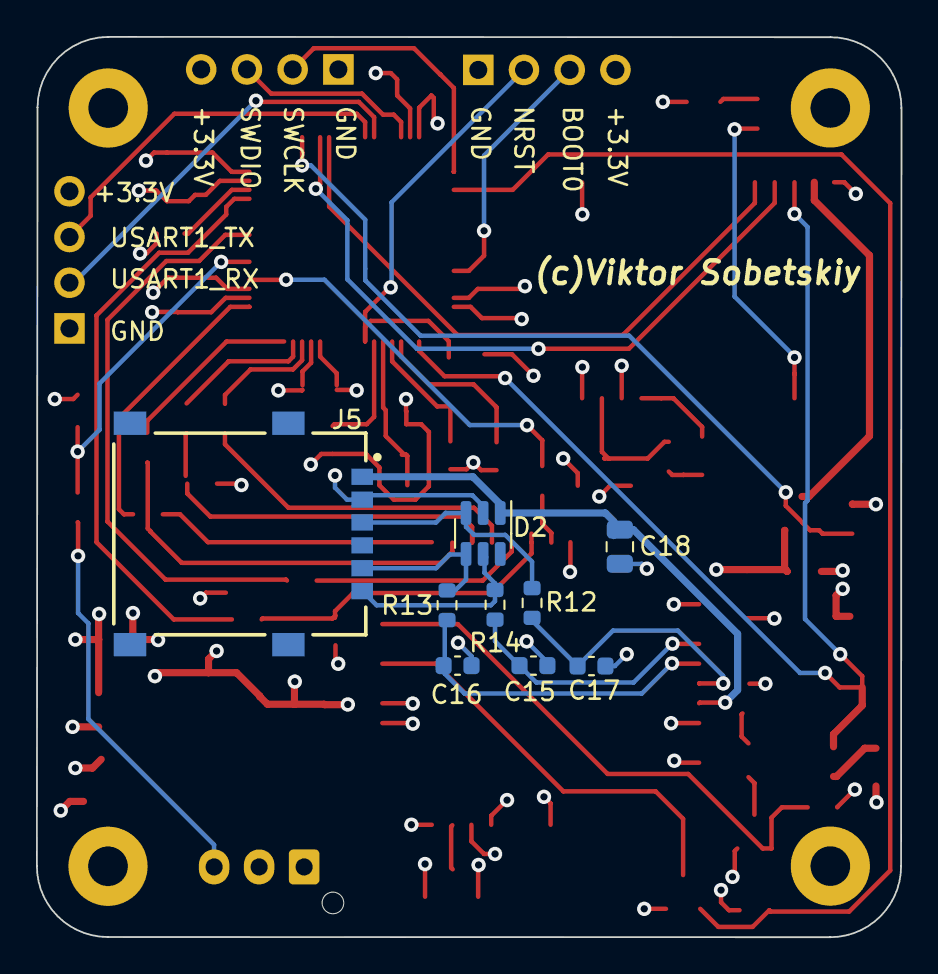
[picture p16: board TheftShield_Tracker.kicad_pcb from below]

Board: 4 copper layers, 48.0 x 50.0 mm, 73 parts (9 on the bottom side), 54 nets.

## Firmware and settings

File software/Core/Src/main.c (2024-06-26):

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
/* Includes ------------------------------------------------------------------*/
#include "main.h"

/* USER CODE BEGIN Includes */

#include "application_tasks.h"

/* USER CODE END Includes */

ADC_HandleTypeDef hadc1;

RTC_HandleTypeDef hrtc;

UART_HandleTypeDef huart1;
UART_HandleTypeDef huart2;
UART_HandleTypeDef huart6;

/* USER CODE BEGIN PV */

UART_HandleTypeDef *sim800_uart = &huart2;
UART_HandleTypeDef *gps_uart = &huart6;


SIM800_Handle_t sim800h = {0};
NEO6M_Handle_t neo6mh = {0};


QueueHandle_t xCommandQueue;
QueueHandle_t xSMSToSendQueue;
QueueHandle_t xNumbersToSendGPSQueue;
QueueHandle_t xNumbersToSendVoltageQueue;
QueueHandle_t xTimeToRTCAlarmQueue;
QueueHandle_t xGPSCoordinatesQueue;
QueueHandle_t xADCValueQueue;

TaskHandle_t xSim800ResetTaskHandle;
TaskHandle_t xCmdProcessTaskHandle;
TaskHandle_t xSendGPSTaskHandle;
TaskHandle_t xSendVoltageTaskHandle;
TaskHandle_t xSendCurrentAlarmTaskHandle;
TaskHandle_t xSendSMSTaskHandle;
TaskHandle_t xConfigRTCAlarmTaskHandle;


uint32_t currentTime = 0;

char phoneNumberForNotify[PHONE_NUMBER_MAX_LENGHT];


/* USER CODE END PV */

void SystemClock_Config(void);
static void MX_GPIO_Init(void);
static void MX_USART1_UART_Init(void);
static void MX_USART2_UART_Init(void);
static void MX_USART6_UART_Init(void);
static void MX_ADC1_Init(void);
static void MX_RTC_Init(void);
/* USER CODE BEGIN PFP */

static void set_current_time(void);

/* USER CODE END PFP */

/**
  * @brief  The application entry point.
  * @retval int
  */
int main(void)
{

  /* MCU Configuration--------------------------------------------------------*/

  /* Reset of all peripherals, Initializes the Flash interface and the Systick. */
  HAL_Init();

  /* Configure the system clock */
  SystemClock_Config();

  /* Initialize all configured peripherals */
  MX_GPIO_Init();
  MX_USART1_UART_Init();
  MX_USART2_UART_Init();
  MX_USART6_UART_Init();
  MX_ADC1_Init();
  MX_RTC_Init();
  /* USER CODE BEGIN 2 */

    set_current_time();

    HAL_RTC_DeactivateAlarm(&hrtc, RTC_ALARM_A);

    xCommandQueue = xQueueCreate(COMMAND_QUEUE_LEGHT, sizeof( SMS_t ));
    xSMSToSendQueue = xQueueCreate(SMS_QUEUE_LEGHT, sizeof( SMS_t ));
    xNumbersToSendGPSQueue = xQueueCreate(SEND_GPS_QUEUE_LENGHT, PHONE_NUMBER_MAX_LENGHT);
    xNumbersToSendVoltageQueue = xQueueCreate(SEND_VOLTAGE_QUEUE_LENGHT, PHONE_NUMBER_MAX_LENGHT);
    xTimeToRTCAlarmQueue = xQueueCreate(ALARM_TIME_QUEUE_LENGHT, sizeof( uint32_t ));
    xGPSCoordinatesQueue = xQueueCreate(GPS_QUEUE_LEGHT, sizeof( Coordinates_t ));
    xADCValueQueue = xQueueCreate(ADC_QUEUE_LEGHT, sizeof( uint32_t ));

    create_tasks();

    vTaskStartScheduler();

  /* USER CODE END 2 */

  /* Infinite loop */
  /* USER CODE BEGIN WHILE */
  while (1)
  {
    /* USER CODE END WHILE */

    /* USER CODE BEGIN 3 */
  }
  /* USER CODE END 3 */
}

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
/* USER CODE BEGIN 4 */

/**
 * @brief  Callback function called when data is received on UART.
 * @param  huart Pointer to the UART handle structure.
 * @retval None
 */
void HAL_UART_RxCpltCallback(UART_HandleTypeDef *huart)
{
  /* Check if the received data is from the SIM800 module */
  if(huart == sim800_uart)
  {
    /* Call the SIM800 message handler */
    SIM800_MessageHandler(&sim800h);
  }
  /* Check if the received data is from the NEO6M GPS module */
  else if( huart == gps_uart )
  {
    /* Call the NEO6M message handler */
    NEO6M_MessageHandler(&neo6mh);
  }
}

/**
 * @brief  Callback function called when ADC conversion is completed.
 * @param  hadc Pointer to the ADC handle structure.
 * @retval None
 */
void HAL_ADC_ConvCpltCallback(ADC_HandleTypeDef* hadc)
{
  uint32_t adc_value = 0;

  /* Get the ADC conversion value */
  adc_value = HAL_ADC_GetValue(hadc);

  /* Send the ADC value to the queue from the interrupt context */
  xQueueSendFromISR( xADCValueQueue, ( void * )&adc_value, NULL );
}

/**
 * @brief  Callback function called when an RMC message is received from the NEO6M GPS module.
 * @param  package Pointer to the RMC package data structure.
 * @retval None
 */
void NEO6M_RMCCallBack(void *package)
{
    RMC_Package_t *rmc_package = (RMC_Package_t *)package;
    Coordinates_t cor = {0};

    /* Check if valid latitude and longitude values are received */
    if( rmc_package->latitude != 0 && rmc_package->longitude != 0 )
    {
        /* Store the coordinates in the local structure */
        cor.latitude = rmc_package->latitude;
        cor.longitude = rmc_package->longitude;

        /* Send the coordinates to the queue from the interrupt context */
        xQueueSendFromISR( xGPSCoordinatesQueue, ( void * ) &cor, NULL );
    }
}

/**
 * @brief  Callback function called when a GLL message is received from the NEO6M GPS module.
 * @param  package Pointer to the GLL package data structure.
 * @retval None
 */
void NEO6M_GLLCallBack(void *package)
{
    GLL_Package_t *gll_package = (GLL_Package_t *)package;

    /* Check if valid latitude and longitude values are received */
    if( gll_package->latitude != 0 && gll_package->longitude != 0 )
    {
        /* Update the current time based on the received time from the GLL message */
        currentTime = gll_package->time + 30000;
        if(currentTime > 240000)
        {
            currentTime -= 240000;
        }
    }
}

/**
 * @brief  Callback function called when a new SMS notification is received by the SIM800 module.
 * @param  handle Pointer to the SIM800 handle structure.
 * @param  sms_index Index of the received SMS message.
 * @retval None
 */
void SIM800_NewSMSNotificationCallBack(SIM800_Handle_t *handle, uint32_t sms_index)
{
    /* Request the SIM800 module to send the received SMS message */
    SIM800_RequestSMSMessage(handle, sms_index);
}

/**
 * @brief  Callback function called when an SMS message is received by the SIM800 module.
 * @param  handle Pointer to the SIM800 handle structure.
 * @param  message Pointer to the received SMS message structure.
 * @retval None
 */
void SIM800_RcvdSMSCallBack(SIM800_Handle_t *handle, SIM800_SMSMessage_t *message)
{
    SMS_t cmd_buff = {0};
    size_t phone_number_size = 0, sms_message_size = 0;

    /* Get the length of the phone number and SMS message */
    phone_number_size = strlen(message->sender);
    sms_message_size = strlen(message->text);

    /* Truncate the phone number if it exceeds the maximum allowed length */
    if( phone_number_size > SMS_SENDER_MAX_LEN)
    {
        message->sender[SMS_SENDER_MAX_LEN] = '\0';
    }

    /* Truncate the SMS message if it exceeds the maximum allowed length */
    if( sms_message_size > SMS_TEXT_MAX_LEN)
    {
        message->text[SMS_TEXT_MAX_LEN] = '\0';
    }

    /* Copy the phone number and SMS message to the command buffer */
    strcpy((char *)&cmd_buff.number, message->sender);
    strcpy((char *)&cmd_buff.message, message->text);

    /* Send the command buffer to the queue from the interrupt context */
    xQueueSendFromISR( xCommandQueue, ( void * ) &cmd_buff, NULL );
}

/**
 * @brief  Callback function called when the RTC alarm event occurs.
 * @param  hrtc Pointer to the RTC handle structure.
 * @retval None
 */
void HAL_RTC_AlarmAEventCallback(RTC_HandleTypeDef *hrtc)
{
    /* Send the phone number for notification to the queue for sending GPS coordinates */
    xQueueSendFromISR( xNumbersToSendGPSQueue, phoneNumberForNotify, 0 );
}

/**
 * @brief  Function to set the current time in the RTC using the GPS module.
 * @param  None
 * @retval None
 */
static void set_current_time(void)
{
    RTC_TimeTypeDef sTime;
    uint8_t hrs = 0, min = 0, sec = 0;

    /* Enable power to the GPS module */
    HAL_GPIO_WritePin(NEO6_PWR_CNTRL_GPIO_Port, NEO6_PWR_CNTRL_Pin, RESET);
    /* Add the GLL message type to the expected message list */
    NEO6M_AddExpectedMessage(&neo6mh, GLL);

    /* Wait until the current time is updated from the GLL message */
    while( !currentTime );

    /* Remove the GLL message type from the expected message list */
    NEO6M_RemoveExpectedMessage(&neo6mh, GLL);
    /* Disable power to the GPS module */
    HAL_GPIO_WritePin(NEO6_PWR_CNTRL_GPIO_Port, NEO6_PWR_CNTRL_Pin, SET);

    /* Extract the hours, minutes, and seconds from the current time */
    hrs = currentTime / 10000;
    min = ( currentTime - hrs * 10000 ) / 100;
    sec = currentTime - ( hrs * 10000 + min * 100 );

    /* Configure the RTC time structure */
    sTime.Hours = hrs;
    sTime.Minutes = min;
    sTime.Seconds = sec;
    sTime.TimeFormat = RTC_HOURFORMAT12_AM;
    sTime.DayLightSaving = RTC_DAYLIGHTSAVING_NONE;
    sTime.StoreOperation = RTC_STOREOPERATION_RESET;

    /* Set the RTC time */
    HAL_RTC_SetTime(&hrtc, &sTime, RTC_FORMAT_BIN);
}


/* USER CODE END 4 */

/**
  * @brief  Period elapsed callback in non blocking mode
  * @note   This function is called  when TIM1 interrupt took place, inside
  * HAL_TIM_IRQHandler(). It makes a direct call to HAL_IncTick() to increment
  * a global variable "uwTick" used as application time base.
  * @param  htim : TIM handle
  * @retval None
  */
void HAL_TIM_PeriodElapsedCallback(TIM_HandleTypeDef *htim)
{
  if (htim->Instance == TIM1) {
    HAL_IncTick();
  }
}

/**
  * @brief  This function is executed in case of error occurrence.
  * @retval None
  */
void Error_Handler(void)
{
  /* USER CODE BEGIN Error_Handler_Debug */
  /* User can add his own implementation to report the HAL error return state */
  __disable_irq();
  while (1)
  {
  }
  /* USER CODE END Error_Handler_Debug */
}

#ifdef  USE_FULL_ASSERT
/**
  * @brief  Reports the name of the source file and the source line number
  *         where the assert_param error has occurred.
  * @param  file: pointer to the source file name
  * @param  line: assert_param error line source number
  * @retval None
  */
void assert_failed(uint8_t *file, uint32_t line)
{
  /* USER CODE BEGIN 6 */
  /* User can add his own implementation to report the file name and line number,
     ex: printf("Wrong parameters value: file %s on line %d\r\n", file, line) */
  /* USER CODE END 6 */
}
#endif /* USE_FULL_ASSERT */

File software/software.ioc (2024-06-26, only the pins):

Mcu.UserName=STM32F401RCTx
PA10.Signal=USART1_RX
PA13.Signal=SYS_JTMS-SWDIO
PA14.Signal=SYS_JTCK-SWCLK
PA2.Signal=USART2_TX
PA3.Signal=USART2_RX
PA6.Signal=ADCx_IN6
PA9.Signal=USART1_TX
PB14.GPIO_Label=NEO6_PWR_CNTRL
PB14.Signal=GPIO_Output
PC10.GPIO_Label=SIM_PWR_CNTRL
PC10.Signal=GPIO_Output
PC14-OSC32_IN.Signal=RCC_OSC32_IN
PC15-OSC32_OUT.Signal=RCC_OSC32_OUT
PC6.Signal=USART6_TX
PC7.Signal=USART6_RX

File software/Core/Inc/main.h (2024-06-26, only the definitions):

#define NEO6_PWR_CNTRL_Pin GPIO_PIN_14
#define NEO6_PWR_CNTRL_GPIO_Port GPIOB
#define SIM_PWR_CNTRL_Pin GPIO_PIN_10
#define SIM_PWR_CNTRL_GPIO_Port GPIOC
#define COMMAND_QUEUE_LEGHT 		5
#define SEND_GPS_QUEUE_LENGHT		5
#define SEND_VOLTAGE_QUEUE_LENGHT	5
#define SMS_QUEUE_LEGHT				5
#define GPS_QUEUE_LEGHT				1
#define ALARM_TIME_QUEUE_LENGHT		1
#define ADC_QUEUE_LEGHT 			1
#define PHONE_NUMBER_MAX_LENGHT		20

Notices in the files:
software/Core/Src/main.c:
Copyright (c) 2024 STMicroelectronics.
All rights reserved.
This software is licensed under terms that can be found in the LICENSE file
